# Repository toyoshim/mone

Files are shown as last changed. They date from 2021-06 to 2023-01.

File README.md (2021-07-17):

# MONE - Mini console Oriented NEOGEO converter

## Overview

This is a small box for you to use NEOGEO gamepad on playing multiple mini consoles.
Currently it supports

- NEOGEO mini
- MEGADRIVE mini
- PC-Engine mini
- Playstation Classic
- Retro-bit Generations IV (and maybe other variants)
- THE C64 MINI

Also it supports features to configure button layout, and assign rapid fire mode for arbitrary buttons.

## Features

### Multiple console supports

MONE is recognized as a USB HID device, and it's device information will change based on DIPSW.
If you change DIPSW, the device will reconnect and the host will recognize the new console mode.

Here is the list for DIPSW.

- 000x: NEOGEO mini
- 100x: MEGADRIVE mini
- 010x: PC-Engine mini
- 110x: Playstation Classic
- 001x: Retro-bit Generations
- 101x: THE C64 MINI
- 011x: (reserved)
- 111x: (reserved)

DIPSW 4 is not used to choose a mini console mode, but you can save layout and rapid fire settings for each.
So, you can have 2 different settings for each console.

### Button Layout

Once you push the button on the PCB, MONE goes into a button layout configuration mode. You can choose arbitray physical button sets for logical button 1, 2, 3, 4, 5, 6, 7, and 8. You can choose multiple physical buttons for one logical button, and can assign one of them as a rapid fire mode, e.g. choosing physical button 1 and 3 for the logical button 1, and button 3 can be a rapid fire button for the 1.

By default, MONE assumes that the physical button layout is something like this:

```
       2     3
  1
      5    6
4
```

And each console mode maps these physical buttons into their own buttons.
Here is the matrix.

| Mode \ Button | COIN |START| 1 | 2 | 3 | 4 | 5 | 6 | 7 | 8 |
|---|---|-----|---|---|---|---|---|---|---|---|
| NEOGEO mini |SELECT|START| B | C | D | A | - | - | - | - |
| MEGADRIVE mini | HOME |START| A | B | C | X | Y | Z | - | - |
| PC-Engine mini |SELECT| RUN |II | I | - | - | - | - | - | - |
| Playstation Classic |SELECT|START| □ | × | ○ | △ |L2 |R2 |L1 |R1 |
| Retro-bit Generations | MODE |START| 1 | 2 | 3 | 4 | 5 | 6 | - | - |
| THE C64 MINI |  C |MENU |LF |RF |TL |TR | A | B | - | - |

You can change the layout for each mode as follows.

Steps:

1. Puth the button on the PCB
2. Push gamepad buttons for the logical coin (e.g. B on NEOGEO mini), and release them
3. Push gamepad buttons for the logical start (e.g. C on NEOGEO mini), and release them
4. Push gamepad buttons for the logical button 1 (e.g. C on NEOGEO mini), and release them
4. Continue for 2, 3, ..., and 8
5. Push the button on the PCB to configure rapid fire buttons

You can quit the layout configuration mode anytime by pushing the button on the PCB.
If you skip all, layout won't be changed, but if you set some buttons partially, remaining buttons are assigned to no button.

### Rapid Fire

After setting the layout mode, you can enter the rapid fire configuration mode.
Push buttons those you want to make it rapid fire buttons, then push the button on the PCB again.
You can got to the rapid fire speed setting mode.

For instance, you can assign physical buttons 1 and 3 to logical button B in the layout mode, and can assign button 3 as a rapid fire button B here. Thus, you can use gamepad button 1 for a normal button B, and use button 3 for a rapid fire button B.

Once you quit the rapid fire configuration mode, now you can choose the rapid fire speed.
Push one of following button to select the speed. Note that the number is for specifying the button in the original physical layout. You can quit the speed setting mode by pushing the button on the PCB. Now you can get back to the normal operation.

| Button |  1 |  2 |  3 |  4 |
|---|----|----|----|----|
| Speed  | 12 | 15 | 20 | 30 |

### Settings

When you finish the layout and rapid fire settings, all configurations are stored into the flash ROM.
You can save the settings per each DIPSW mode, that means you can keep 2 settings for each console mode.

### 6 Buttons

The original NEOGEO has only 4 buttons, but there are unused pins. MONE uses these unused pins for button 5 and 6.
This is the same with some Japanese arcade control boxes. See the schematics below to check details.

Also, complete KiCad data is available in the repository so to order your own PCB.

## Schematics
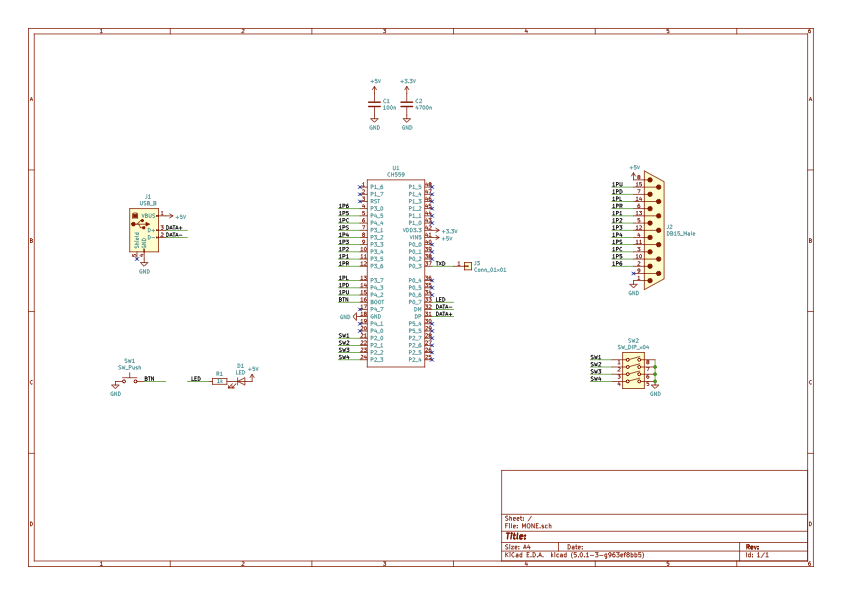
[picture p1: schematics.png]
schematics


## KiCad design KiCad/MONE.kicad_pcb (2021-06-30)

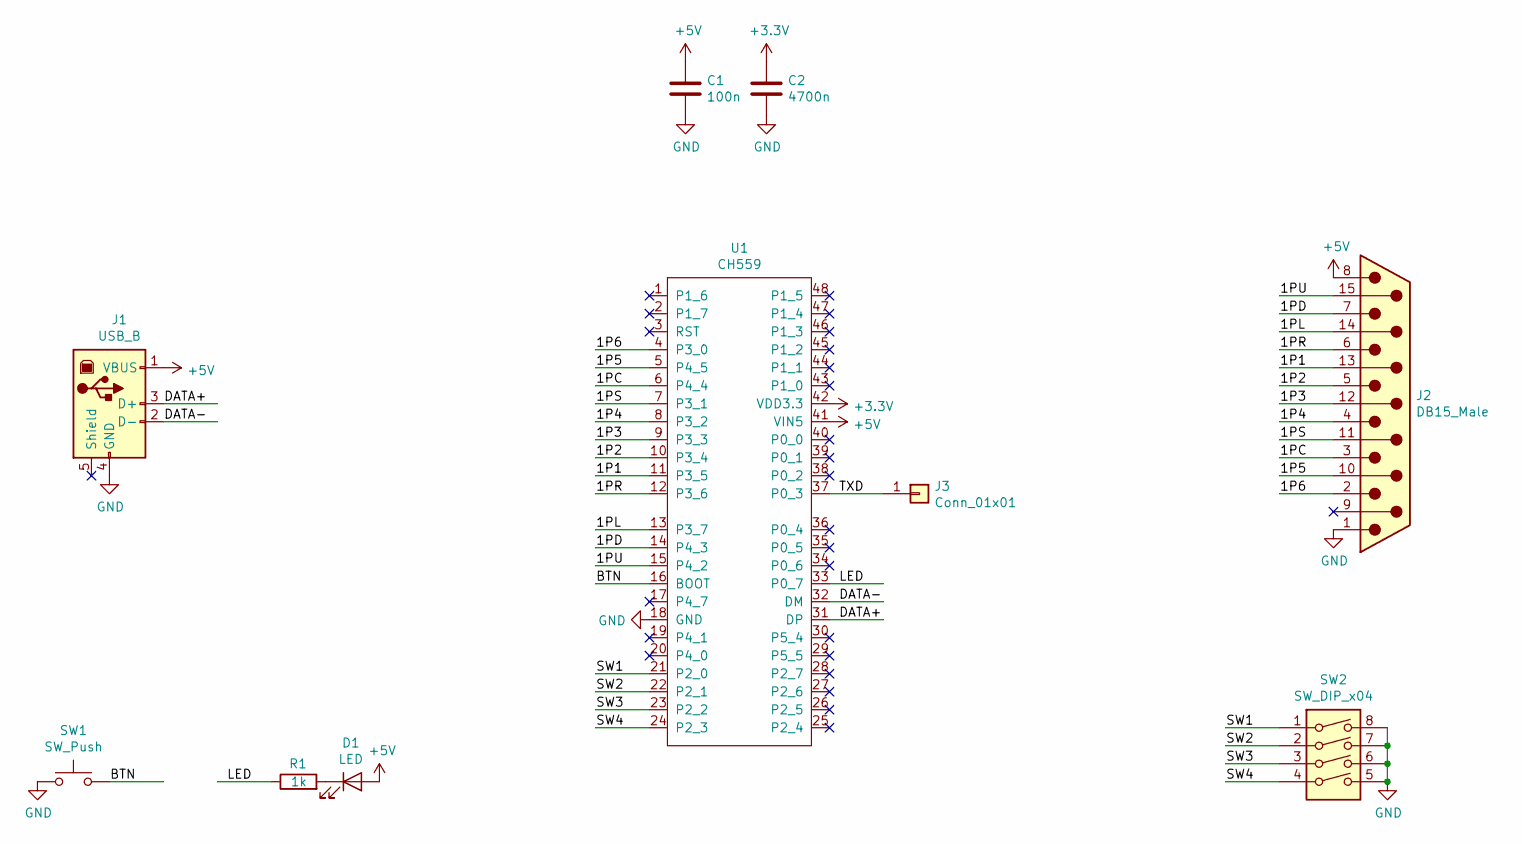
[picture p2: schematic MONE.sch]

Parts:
C1: 100n; C_0603_1608Metric_Pad1.05x0.95mm_HandSolder
C2: 4700n; C_0603_1608Metric_Pad1.05x0.95mm_HandSolder
D1: LED; LED_D3.0mm
J1: USB_B; USB_B_OST_USB-B1HSxx_Horizontal
J2: DB15_Male; DSUB-15_Male_Horizontal_P2.77x2.84mm_EdgePinOffset4.94mm_Ho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
J3: Conn_01x01; PinHeader_1x01_P2.54mm_Vertical
R1: 1k; R_0603_1608Metric_Pad1.05x0.95mm_HandSolder
SW1: SW_Push; SW_PUSH_6mm_H4.3mm
SW2: SW_DIP_x04; SW_DIP_SPSTx04_Slide_9.78x12.34mm_W7.62mm_P2.54mm
U1: CH559; LQFP-48_7x7mm_P0.5mm

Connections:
+3V3: C2.1, U1.42 (VDD3.3)
+5V: C1.1, D1.2 (A), J1.1 (VBUS), J2.8, U1.41 (VIN5)
/1P1: J2.13, U1.11 (P3_5)
/1P2: J2.5, U1.10 (P3_4)
/1P3: J2.12, U1.9 (P3_3)
/1P4: J2.4, U1.8 (P3_2)
/1P5: J2.10, U1.5 (P4_5)
/1P6: J2.2, U1.4 (P3_0)
/1PC: J2.3, U1.6 (P4_4)
/1PD: J2.7, U1.14 (P4_3)
/1PL: J2.14, U1.13 (P3_7)
/1PR: J2.6, U1.12 (P3_6)
/1PS: J2.11 (P111), U1.7 (P3_1)
/1PU: J2.15, U1.15 (P4_2)
/BTN: SW1.2, U1.16 (BOOT)
/DATA+: J1.3 (D+), U1.31 (DP)
/DATA-: J1.2 (D-), U1.32 (DM)
/LED: R1.1, U1.33 (P0_7)
/SW1: SW2.1, U1.21 (P2_0)
/SW2: SW2.2, U1.22 (P2_1)
/SW3: SW2.3, U1.23 (P2_2)
/SW4: SW2.4, U1.24 (P2_3)
/TXD: J3.1, U1.37 (P0_3)
GND: C1.2, C2.2, J1.4 (GND), J2.1, SW1.1, SW2.5, SW2.6, SW2.7, SW2.8, U1.18 (GND)
unnamed: D1.1 (K), R1.2

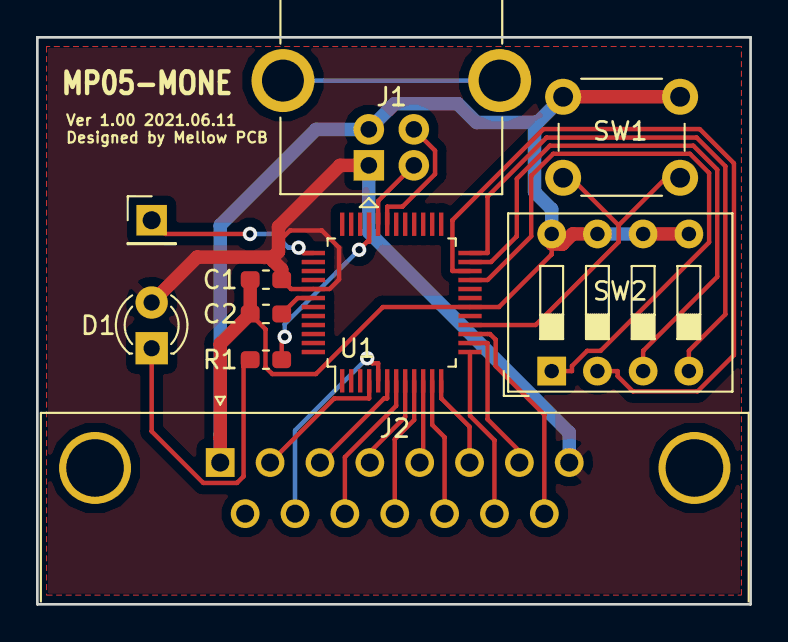
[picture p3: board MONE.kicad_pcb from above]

Board: 2 copper layers, 39.6 x 31.5 mm, 10 parts (0 on the bottom side), 25 nets.

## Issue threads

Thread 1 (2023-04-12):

The resolution of schematics.png is low.

shobobon, 2023-04-12:
I would like a more detailed image
The detail section is unreadable.

Thank you for your consideration on the matter.

shobobon, 2023-04-12:
I referenced the kicad file. I am sorry.

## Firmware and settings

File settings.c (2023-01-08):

// Copyright 2021 Takashi Toyoshima <toyoshim@gmail.com>. All rights reserved.
// Use of this source code is governed by a BSD-style license that can be found
// in the LICENSE file.

#include "settings.h"

#include "ch559.h"
#include "flash.h"
#include "led.h"
#include "timer3.h"

#include "controller.h"

static uint8_t mode = S_NORMAL;
static uint8_t mode_step = 0;
static uint16_t mode_data = 0;
static uint8_t mode_dipsw = 0;
static uint8_t usb_mode = U_NEOGEO_MINI;
static bool rapid_fire = false;
static uint16_t rapid_msec = 0;
static uint16_t poll_msec = 0;
static const uint16_t poll_interval = 17;
static uint8_t last_button = 0;

struct setting settings[16];

static uint8_t dipsw() {
  return ~digitalReadPort(2) & 0x0f;
}

static void mode_layout() {
  uint16_t buttons = controller_get() & 0x03ff;
  if (mode_data && !buttons) {
    if (mode_step < 10) {
      uint8_t index = (mode_step < 2) ? mode_step : (mode_step + 4);
      settings[mode_dipsw].button_masks[index] = mode_data;
      led_mode(L_FASTER_BLINK);
    }
    mode_data = 0;
    mode_step++;
  }
  mode_data |= buttons;
  if (mode_data)
    led_mode(L_OFF);
}

static void quit_layout() {
  if (mode_step == 0)
    return;
  for (uint8_t i = mode_step; i < 8; ++i)
    settings[mode_dipsw].button_masks[B_1 + i] = 0;
}

static void mode_rapid() {
  uint16_t buttons = controller_get() & 0x3ff;
  if (mode_data && !buttons) {
    settings[mode_dipsw].rapid_fire = mode_data;
    led_mode(L_FAST_BLINK);
    mode_data = 0;
  }
  mode_data |= buttons;
  if (mode_data)
    led_mode(L_OFF);
}

static void mode_speed() {
  uint16_t buttons = controller_get() & 0x3ff;
  if (buttons & 0x0040) {
    settings[mode_dipsw].speed = 17;  // 30
  } else if (buttons & 0x0080) {
    settings[mode_dipsw].speed = 25;  // 20
  } else if (buttons & 0x0100) {
    settings[mode_dipsw].speed = 33;  // 15
  } else if (buttons & 0x0200) {
    settings[mode_dipsw].speed = 42;  // 12
  }
  led_mode((buttons & 0x03c0) ? L_OFF : L_BLINK);
}

static void quit_speed() {
  settings_save();
}

static void slow_poll() {
  poll_msec += poll_interval;
  uint8_t button = digitalRead(4, 6);
  if (last_button & !button) {
    switch (mode) {
      case S_LAYOUT:
        quit_layout();
        break;
      case S_SPEED:
        quit_speed();
        break;
    }
    mode = (mode + 1) % S_NOT_ASSIGNED;
    mode_step = 0;
    mode_data = 0;
    mode_dipsw = dipsw();
    switch (mode) {
      case S_NORMAL:
        led_mode(L_ON);
        break;
      case S_LAYOUT:
        led_mode(L_FASTER_BLINK);
        break;
      case S_RAPID:
        led_mode(L_FAST_BLINK);
        break;
      case S_SPEED:
        led_mode(L_BLINK);
        break;
    }
  }
  switch (mode) {
    case S_LAYOUT:
      mode_layout();
      break;
    case S_RAPID:
      mode_rapid();
      break;
    case S_SPEED:
      mode_speed();
      break;
  }
  last_button = button;
}

void settings_init() {
  led_init(0, 7, LOW);

  // Setup for a button
  pinMode(4, 6, INPUT_PULLUP);

  // Setup for DIPSW
  for (uint8_t pin = 0; pin <= 3; ++pin)
    pinMode(2, pin, INPUT_PULLUP);

  // Initialize data in flash, and get a copy
  flash_init(*(uint32_t*)"MONE");
  flash_read(4, (uint8_t*)settings, sizeof(settings));
  bool dirty = false;
  for (uint8_t i = 0; i < 16; ++i) {
    if (settings[i].mode != 0xff)
      continue;
    dirty = true;
    settings[i].speed = 17;
    settings[i].rapid_fire = 0;
    settings[i].button_masks[ 0] = (uint16_t)1 << 15;  // Coin
    settings[i].button_masks[ 1] = (uint16_t)1 << 14;  // Start
    settings[i].button_masks[ 2] = (uint16_t)1 << 13;  // Up
    settings[i].button_masks[ 3] = (uint16_t)1 << 12;  // Down
    settings[i].button_masks[ 4] = (uint16_t)1 << 11;  // Left
    settings[i].button_masks[ 5] = (uint16_t)1 << 10;  // Right
    settings[i].button_masks[ 6] = (uint16_t)1 <<  9;  // 1
    settings[i].button_masks[ 7] = (uint16_t)1 <<  8;  // 2
    settings[i].button_masks[ 8] = (uint16_t)1 <<  7;  // 3
    settings[i].button_masks[ 9] = (uint16_t)1 <<  6;  // 4
    settings[i].button_masks[10] = (uint16_t)1 <<  5;  // 5
    settings[i].button_masks[11] = (uint16_t)1 <<  4;  // 6
    settings[i].button_masks[12] = (uint16_t)1 <<  3;  // 7
    settings[i].button_masks[13] = (uint16_t)1 <<  2;  // 8
    for (uint8_t j = 0; j < 8; ++j)
      settings[i].padding[j] = 0;
    settings[i].mode = i & 7;
  }
  if (dirty)
    settings_save();

  usb_mode = dipsw();
  last_button = digitalRead(4, 6);
  rapid_msec = poll_msec = timer3_tick_msec();
}

void settings_save() {
  // Store settings to flash
  flash_write(4, (const uint8_t*)settings, sizeof(settings));
}

uint16_t settings_mask() {
  if (mode != S_NORMAL)
    return 0;
  return rapid_fire ? ~settings_current()->rapid_fire : 0xffff;
}

struct setting* settings_current() {
  return &settings[usb_mode];
}
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

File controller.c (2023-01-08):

// Copyright 2021 Takashi Toyoshima <toyoshim@gmail.com>. All rights reserved.
// Use of this source code is governed by a BSD-style license that can be found
// in the LICENSE file.

#include "controller.h"

#include "ch559.h"

void controller_init() {
  for (uint8_t pin = 0; pin <= 7; ++pin)
    pinMode(3, pin, INPUT_PULLUP);
  for (uint8_t pin = 2; pin <= 5; ++pin)
    pinMode(4, pin, INPUT_PULLUP);
}

uint16_t controller_get() {         // 7654 3210 bit
  uint8_t p3 = digitalReadPort(3);  // LR12 34S6
  uint8_t p4 = digitalReadPort(4);  // --5C DU--
  uint16_t buttons = 0x0f |  // CSUD LP12 3456 ----
      ((p4 & 0x10) << 11) |  // Coin
      ((p3 & 0x02) << 13) |  // Start
      ((p4 & 0x04) << 11) |  // Up
      ((p4 & 0x08) <<  9) |  // Down
      ((p3 & 0xfd) <<  4) |  // Left, Right, 1, 2, 3, 4, 6
       (p4 & 0x20);          // 5
  return ~buttons;
}

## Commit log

2021-06-20 add dipsw and button handling
2021-06-20 implement led service
2021-06-26 move led.* to chlib
2021-06-27 move button related enums to settings.h
2021-06-28 settings: do not reset layout if completely skipped
    [settings.c]
2021-06-30 Add KiCad data
    [MONE.kicad_pcb, MONE.sch]
